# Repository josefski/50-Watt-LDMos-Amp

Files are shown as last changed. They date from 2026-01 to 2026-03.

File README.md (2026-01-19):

# 50-Watt-LDMos-Amp
Inspiration for this project came from here: https://ludens.cl/Electron/50Wamp/50Wamp.html 

A 50 Watt HF Amp that uses modern parts 

This is mostly clanker code for a raspberry pi pico controlled protection loop and operation control for a 50 watt HF Amplifier that uses modern LDmos transistors instead of the IRF series mosfets that are 50 years old and inappropriate for this purpose. 

This is ultimately intended for use as a portable amplifier aimed at SOTA and to a lesser extent POTA operators who want to add some power to their QMX or other QRP radios. The majority of designs available on the internet are built around the IRF 510 or IRF 530 mosfet, and while it's impressive that an hf amp can be built around those parts, they're not very well suited to the purpose. This is designed around the AFT05MP Dual LDmos from NXP, which is currently not recommended for new designs. It's a dual ldmos rf amplifier designed to work up to 530 Mhz. Another rf power transistor that could be substituted would be the BLP5LA55 series LDMOS from Ampleon, which are newer but don't come in the handy dual package. There aren't a lot of 12-15 volt RF mosfets on the market. We're a small niche.  

Principle design goals are as follows: 

-12 volt operation
-Uses actual RF power transistors, preferably ldmos
-No unobtainium parts
-Currently manufactured components only
-Keep parts reasonably affordable
-Smaller heatsink with shortened fins and permanently mounted cooling fans for improved portability 
-Ruggedized, completed design, meaning full protections from drain overvoltage, overcurrent, oscillation, and overtemperature
-Able to be used in line with an antenna tuner!!!!!!!! (Seriously. A portable amp is next to useless without that capability. Finish the design job.) 
-40-10meter operation. Requires only three filter banks. Don't care about the other bands. This is for portable use. 50 watts won't get you over the noise floor on 80 meters anyway.  
-A real Keyer input. No RF sense keying. It's annoying to use. 
-Manual band switching. 
-Always <2:1 input SWR. The amp should never under any circumstance cause the QMX to shut off. 
-Amp shuts off in response to excess current and drain voltage excursions, not high SWR. High SWR doesn't kill transistors. High drain voltage and overcurrent does. 
-Display all relevant parameters and return comprehensible error codes 
-Maybe full QSK. We'll see. Would be nice but not a specific deal breaker. 
-Maybe Variable input attenuation to compensate for QMX low output on 17 and 21 meters. Cool idea but requires some deep thought.

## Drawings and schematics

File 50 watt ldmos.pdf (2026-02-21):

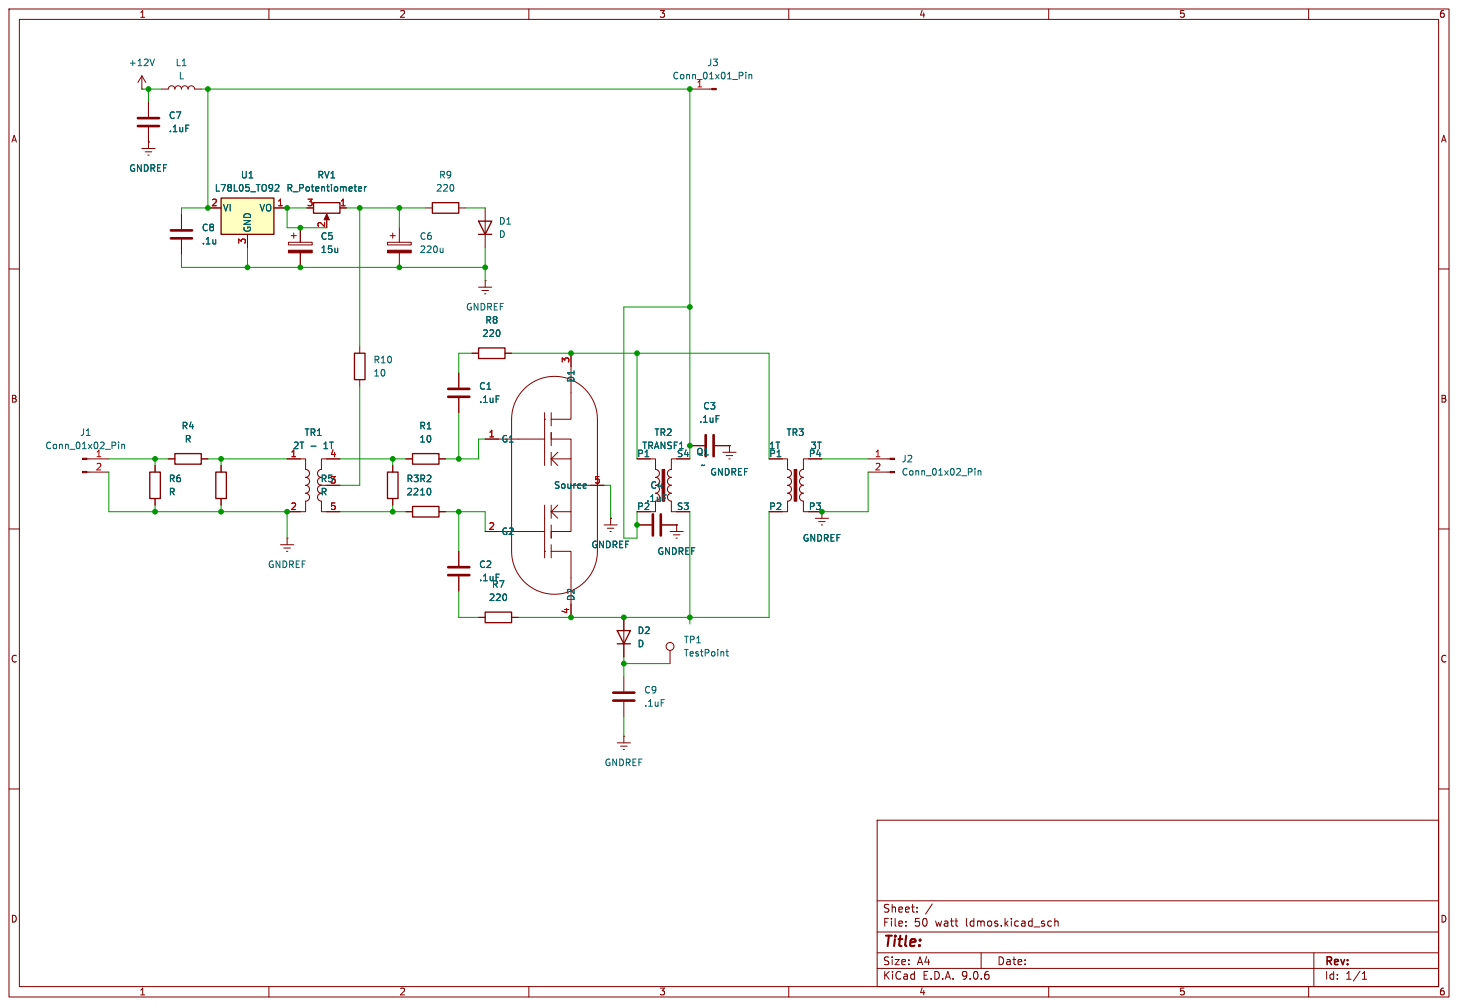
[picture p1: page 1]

4 Source 5 Q1~ R5 R GNDREF VI 2 GND

Id: 1/1 Title: File: 50 watt ldmos.kicad_sch Sheet: /

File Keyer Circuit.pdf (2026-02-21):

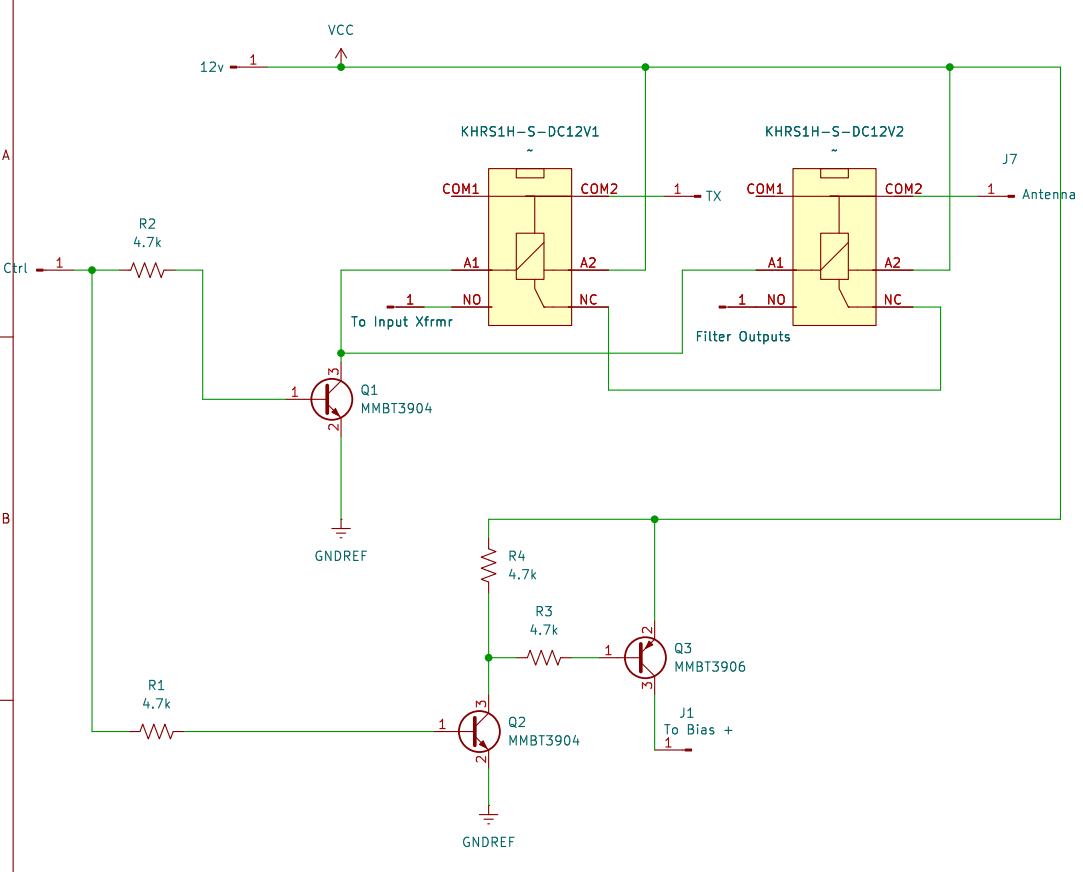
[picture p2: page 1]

Filter Outputs 1 To Input Xfrmr 1

Id: 1/1 Title: File: Keyer Circuit.kicad_sch Sheet: /

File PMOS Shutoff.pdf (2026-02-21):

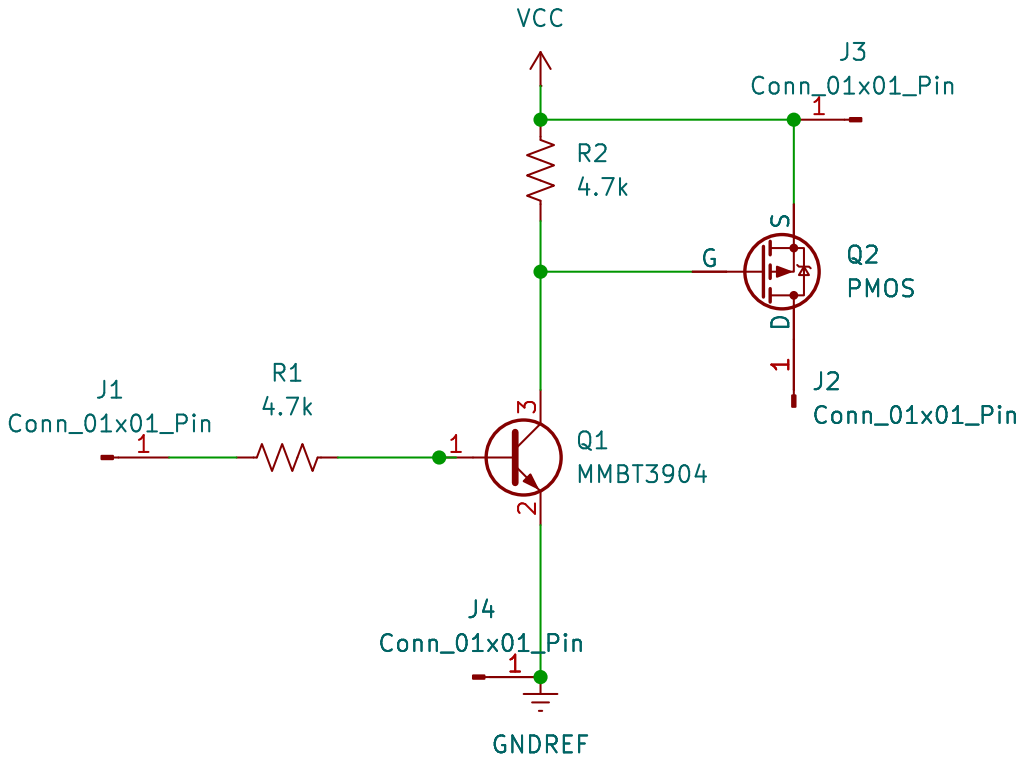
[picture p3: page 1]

Id: 1/1 Title: File: PMOS Shutoff.kicad_sch Sheet: /

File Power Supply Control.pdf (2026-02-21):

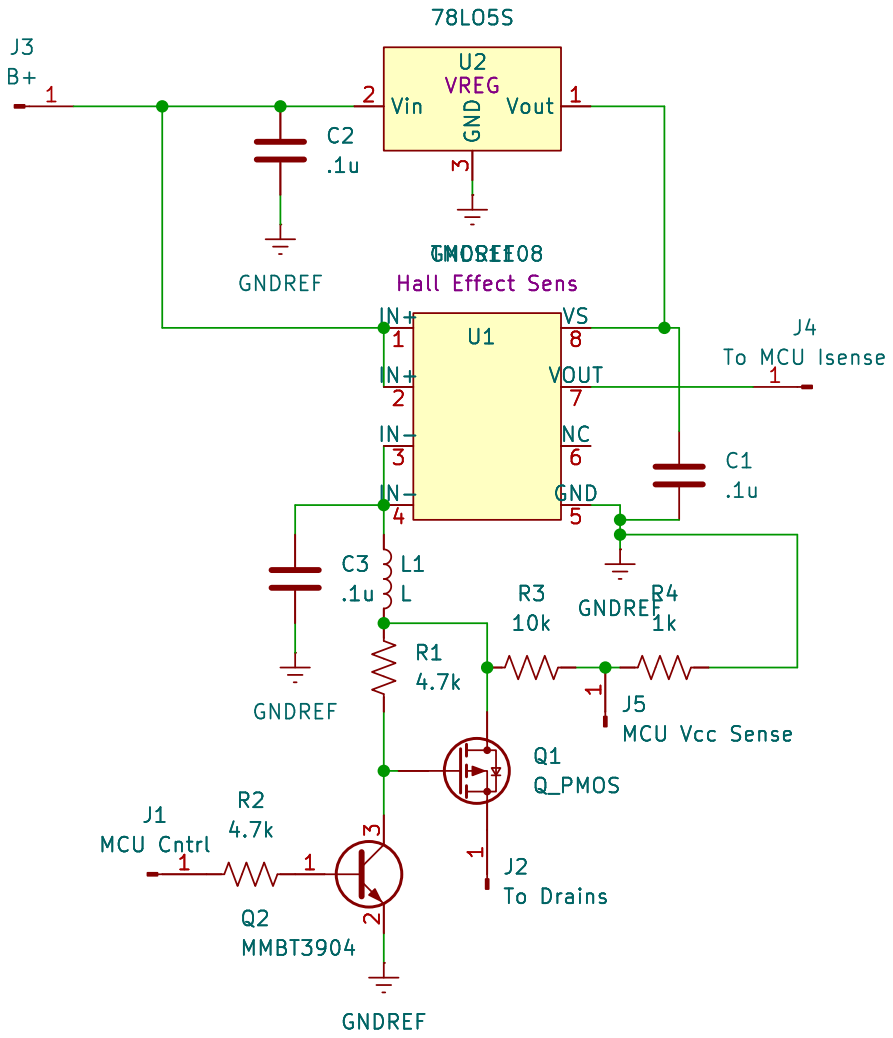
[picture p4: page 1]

J4 To MCU Isense GNDREF
8 VOUT

Id: 1/1 Title: File: Power Supply Control.kicad_sch Sheet: /

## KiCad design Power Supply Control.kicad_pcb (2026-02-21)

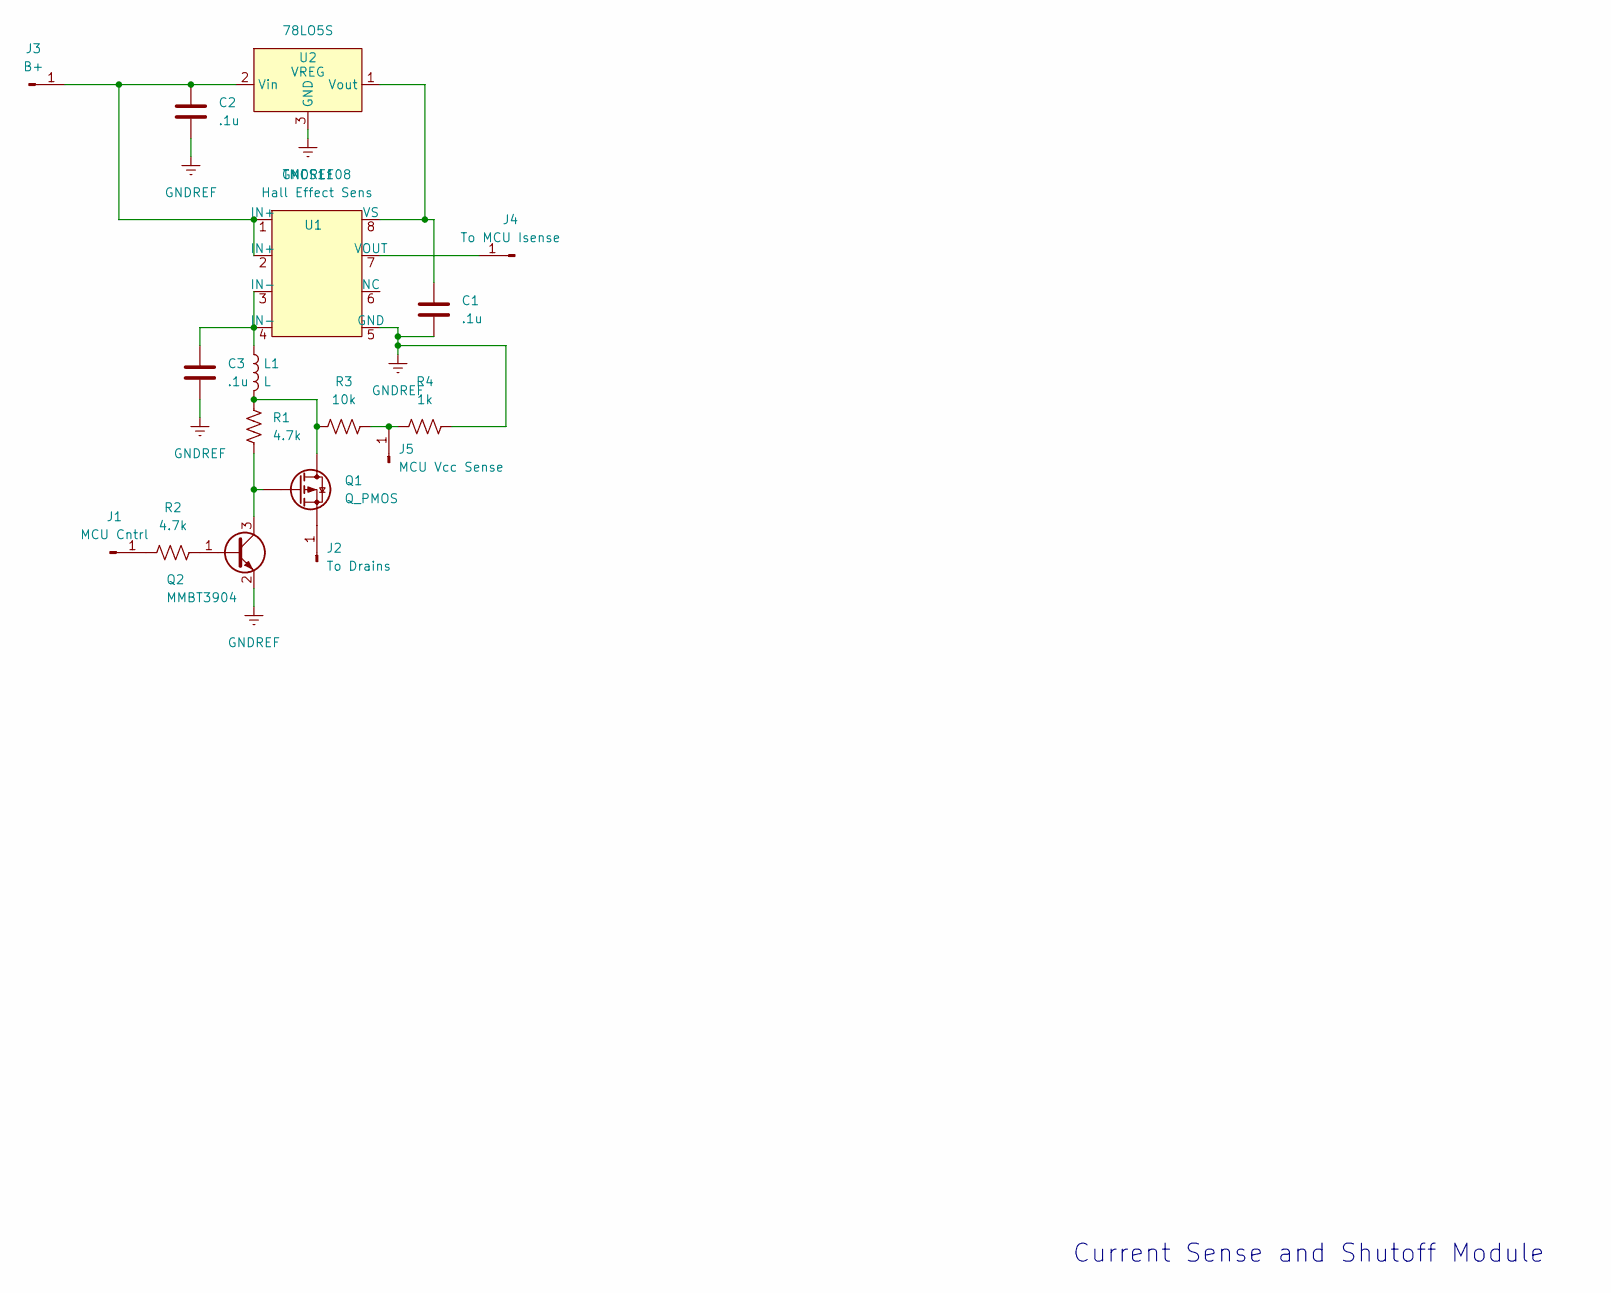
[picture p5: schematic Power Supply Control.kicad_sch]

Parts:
C1, C2: .1u; C_0805_2012Metric_Pad1.18x1.45mm_HandSolder
C3: .1u; .33uF Decoupler HF Amp
J1: MCU Cntrl; Single Surface Mount Header
J2: To Drains; Single Surface Mount Header
J3: B+; Single Surface Mount Header
J4: To MCU Isense; Single Surface Mount Header
J5: MCU Vcc Sense; Single Surface Mount Header
L1: L; Input Choke
Q1: Q_PMOS; Josef TO-252-2
Q2: MMBT3904; SOT-23
R1, R2: 4.7k; R_0805_2012Metric_Pad1.20x1.40mm_HandSolder
R3: 10k; R_0805_2012Metric_Pad1.20x1.40mm_HandSolder
R4: 1k; R_0805_2012Metric_Pad1.20x1.40mm_HandSolder
U1: TMCS1108; SOIC-8 Hall Effect Footprint
U2: 78LO5S; SOT-23

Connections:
GNDREF: C1.2, C2.2, C3.2, Q2.2 (E), R4.2, U1.5 (GND), U2.3 (GND)
unnamed: C3.1, L1.1, U1.3 (IN-), U1.4 (IN-)
unnamed: J1.1, R2.1
unnamed: J2.1, Q1.1 (S)
unnamed: C2.1, J3.1, U1.1 (IN+), U1.2 (IN+), U2.2 (Vin)
unnamed: J4.1, U1.7 (VOUT)
unnamed: J5.1, R3.2, R4.1
unnamed: L1.2, Q1.3 (D), R1.1, R3.1
unnamed: Q1.2 (G), Q2.3 (C), R1.2
unnamed: Q2.1 (B), R2.2
unnamed: C1.1, U1.8 (VS), U2.1 (Vout)

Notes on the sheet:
Current Sense and Shutoff Module

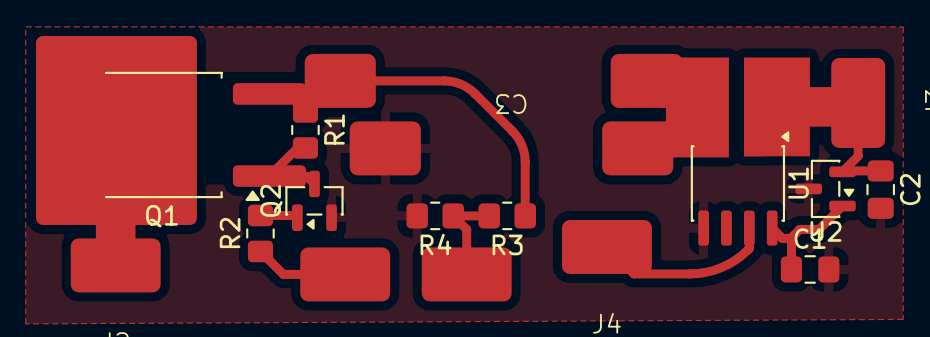
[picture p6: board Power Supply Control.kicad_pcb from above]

Board: 2 copper layers, 17 parts (0 on the bottom side), 11 nets.

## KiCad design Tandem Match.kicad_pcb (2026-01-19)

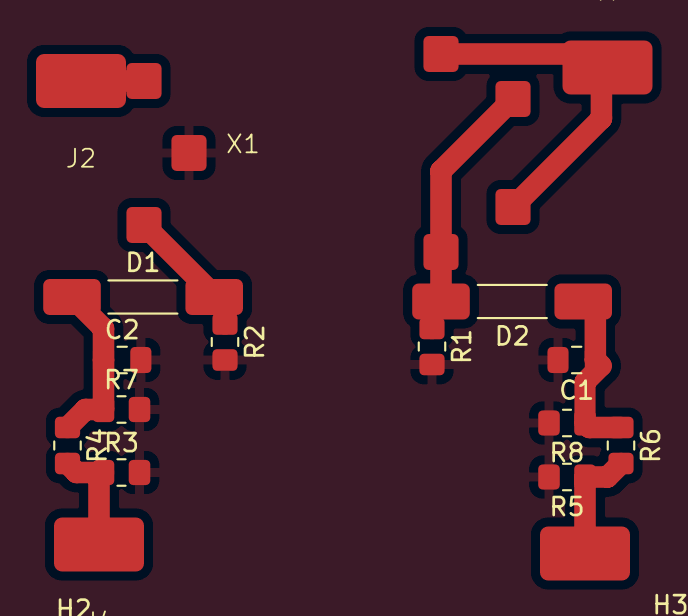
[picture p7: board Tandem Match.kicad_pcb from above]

Board: 2 copper layers, 21 parts (0 on the bottom side), 9 nets.

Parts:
C1, C2: .1u; C_0805_2012Metric_Pad1.18x1.45mm_HandSolder
D1, D2: D; Through Hole Resistor
H1, H2, H3, H4: MountingHole_Pad; MountingHole_3.2mm_M3
J1, J2, J3, J4: Conn_01x01_Pin; Single Surface Mount Header
R1, R2: 50; R_0805_2012Metric_Pad1.20x1.40mm_HandSolder
R3, R5, R7, R8: 10k; R_0805_2012Metric_Pad1.20x1.40mm_HandSolder
R4, R6: 33k; R_0805_2012Metric_Pad1.20x1.40mm_HandSolder
X1: Tandem Match

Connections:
GNDREF: C1.2, C2.2, R1.2, R2.2, R3.2, R5.2, R7.2, R8.2, X1.3 (S)
unnamed: D1.2 (A), R2.1, X1.2
unnamed: C2.1, D1.1 (K), R4.1, R7.1
unnamed: D2.2 (A), R1.1, X1.4, X1.6 (P2_Out)
unnamed: C1.1, D2.1 (K), R6.1, R8.1
unnamed: J1.1, X1.5, X1.7 (P1_Out)
unnamed: J2.1, X1.1
unnamed: J3.1, R5.1, R6.2
unnamed: J4.1, R3.1, R4.2

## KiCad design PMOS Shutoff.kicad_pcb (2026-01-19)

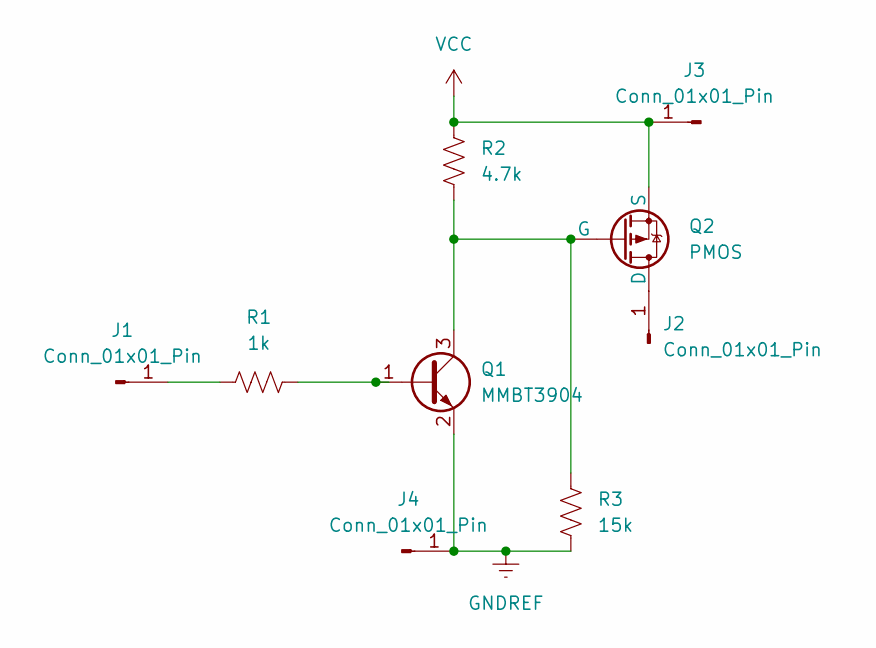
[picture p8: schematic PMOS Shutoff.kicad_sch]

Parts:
J1, J2, J3, J4: Conn_01x01_Pin; Single Surface Mount Header
Q1: MMBT3904; SOT-23
Q2: PMOS; Josef TO-252-2
R1: 1k; R_0805_2012Metric_Pad1.20x1.40mm_HandSolder
R2: 4.7k; R_0805_2012Metric_Pad1.20x1.40mm_HandSolder
R3: 15k; R_0805_2012Metric_Pad1.20x1.40mm_HandSolder

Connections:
GNDREF: J4.1, Q1.2 (E), R3.1
unnamed: J1.1, R1.1
unnamed: J2.1, Q2.1 (D)
unnamed: Q1.1 (B), R1.2
unnamed: Q1.3 (C), Q2.2 (G), R2.1, R3.2
VCC: J3.1, Q2.3 (S), R2.2

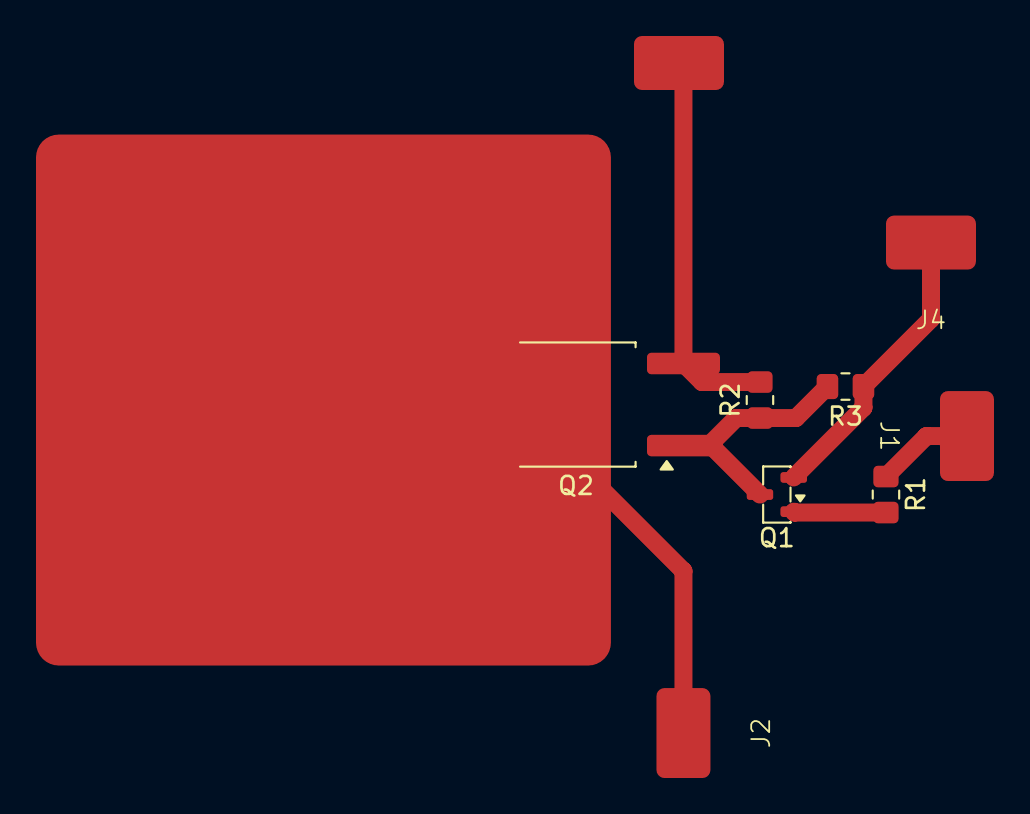
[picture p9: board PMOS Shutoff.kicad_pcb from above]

Board: 2 copper layers, 9 parts (0 on the bottom side), 6 nets.

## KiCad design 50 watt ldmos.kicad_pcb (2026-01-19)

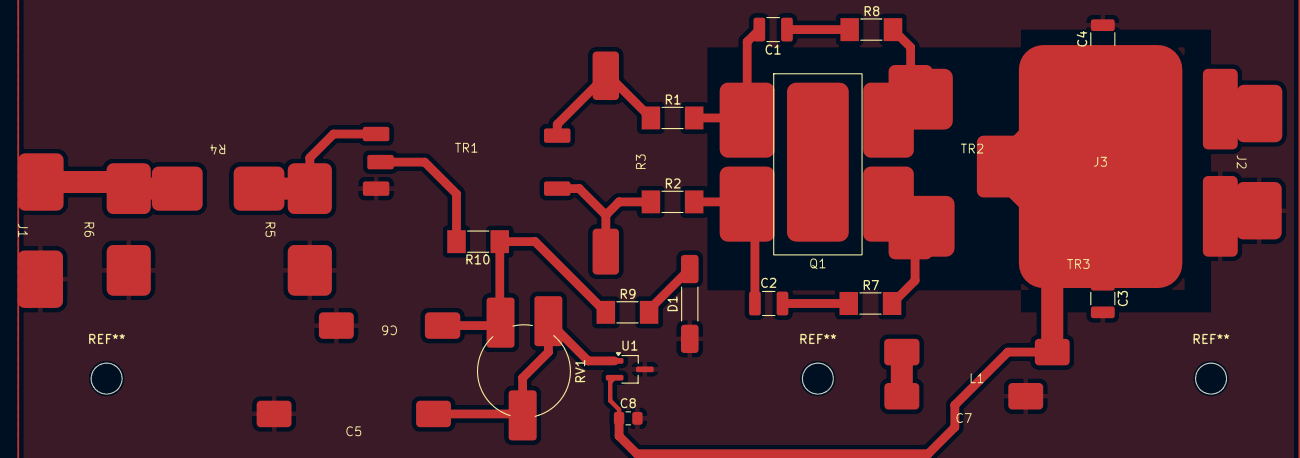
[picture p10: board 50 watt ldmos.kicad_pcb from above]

Board: 2 copper layers, 29 parts (0 on the bottom side), 18 nets.

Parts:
C1, C2, C3, C4: .1uF; C_1210_3225Metric_Pad1.33x2.70mm_HandSolder
C5: 15u; 10uF Radial Cap
C6: 220u; 220 uf Cap
C7: .1uF; .33uF Decoupler HF Amp
C8: .1u; C_0805_2012Metric_Pad1.18x1.45mm_HandSolder
D1: D; Through Hole Resistor
J1, J2: Conn_01x02_Pin; InOutNoHeaders
J3: Conn_01x01_Pin; Positive Plane
L1: L; Input Choke
Q1: AFT05MP
R1, R2, R10: 10; R_MELF_MMB-0207
R3: 22; Big 22ohm Resistor
R4, R5, R6: R; 3550 (Big Resistor) Footprint
R7, R8, R9: 220; R_MELF_MMB-0207
RV1: R_Potentiometer; Piher Surface Pads
TR1: 2T - 1T; Input Transformer
TR2: TRANSF1; Coaxial Feed Transformer
TR3: 1T 3T; Output Transformer
U1: L78L05_TO92; TSOT-23_HandSoldering

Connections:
+12V: C7.1, L1.1
GNDREF: C3.2, C4.2, C5.2, C6.2, C7.2, C8.2, D1.1 (K), J1.2, J2.2, Q1.5 (Source), R5.1, R6.1, TR1.2, TR3.3, U1.3 (GND)
unnamed: C1.1, R8.1
unnamed: C2.2, R7.1
unnamed: C6.1, R9.1, R10.1, RV1.1
unnamed: D1.2 (A), R9.2
unnamed: J1.1, R4.1, R6.2
unnamed: J2.1, TR3.4
unnamed: Q1.3 (D1), R8.2, TR2.1, TR3.1
unnamed: Q1.4 (D2), R7.2, TR2.3 (S3), TR3.2
unnamed: C1.2, Q1.1 (G1), R1.2
unnamed: C2.1, Q1.2 (G2), R2.2
unnamed: R1.1, R3.2, TR1.4
unnamed: R2.1, R3.1, TR1.5
unnamed: R4.2, R5.2, TR1.1
unnamed: R10.2, TR1.3
unnamed: C3.1, C4.1, C8.1, L1.2, TR2.2, TR2.4 (S4), U1.2 (VI)
unnamed: C5.1, RV1.2, RV1.3, U1.1 (VO)

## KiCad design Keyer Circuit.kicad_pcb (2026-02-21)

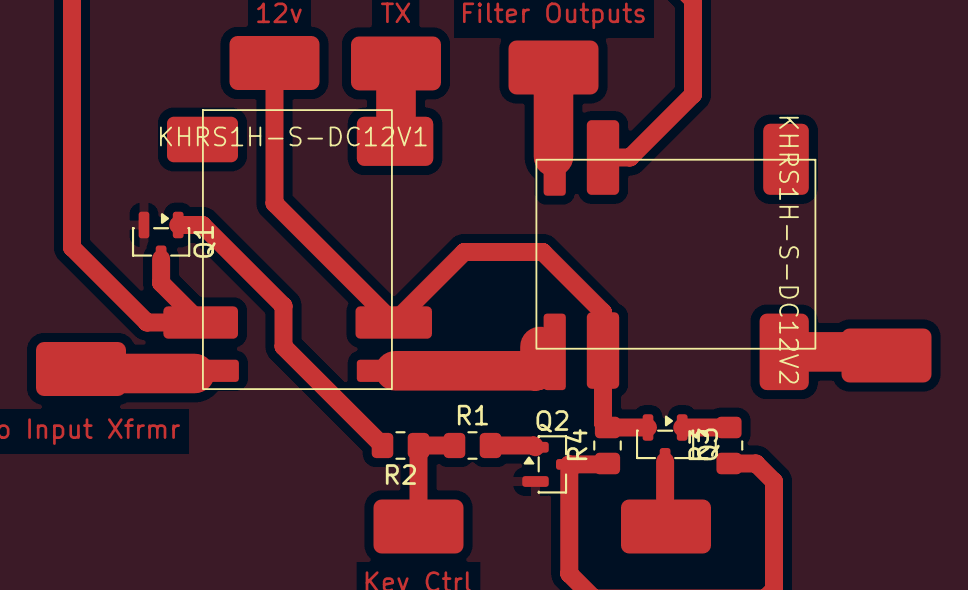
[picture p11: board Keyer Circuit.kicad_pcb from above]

Board: 2 copper layers, 16 parts (0 on the bottom side), 14 nets.

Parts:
J1: To Bias +; Single Surface Mount Header
J2: To Input Xfrmr; Single Surface Mount Header
J3: Key Ctrl; Single Surface Mount Header
J4: Filter Outputs; Single Surface Mount Header
J7: Antenna; Single Surface Mount Header
J8: TX; Single Surface Mount Header
J9: 12v; Single Surface Mount Header
KHRS1H-S-DC12V1, KHRS1H-S-DC12V2: HRS1H Relay No Hole
Q1, Q2: MMBT3904; SOT-23
Q3: MMBT3906; SOT-23
R1, R2, R3, R4: 4.7k; R_0805_2012Metric_Pad1.20x1.40mm_HandSolder

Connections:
GNDREF: Q1.2 (E), Q2.2 (E)
unnamed: J1.1, Q3.3 (C)
unnamed: J2.1, KHRS1H-S-DC12V1.NO
unnamed: J3.1, R1.1, R2.1
unnamed: J4.1, KHRS1H-S-DC12V2.NO
unnamed: J7.1, KHRS1H-S-DC12V2.COM2
unnamed: J8.1, KHRS1H-S-DC12V1.COM2
unnamed: KHRS1H-S-DC12V1.NC, KHRS1H-S-DC12V2.NC
unnamed: Q1.1 (B), R2.2
unnamed: KHRS1H-S-DC12V1.A1, KHRS1H-S-DC12V2.A1, Q1.3 (C)
unnamed: Q2.1 (B), R1.2
unnamed: Q2.3 (C), R3.1, R4.1
unnamed: Q3.1 (B), R3.2
VCC: J9.1, KHRS1H-S-DC12V1.A2, KHRS1H-S-DC12V2.A2, Q3.2 (E), R4.2

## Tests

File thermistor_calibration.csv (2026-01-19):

Temperature | 31.5 | 36 | 39 | 40 | 45 | 66.8 | 68 | 70 | 80 | 90 | 100 | 110 | 120 | 130 | 140 | 150 | 160 | 170 | 180 | 190 | 200 | 210 | 212
Resistance | 27100 | 25000 | 24000 | 21000 | 17800 | 10200 | 9800 | 9100 | 7000 | 5600 | 4700 | 3800 | 3100 | 2700 | 2200 | 1860 | 1500 | 1420 | 1250 | 1100 | 970 | 860 | 850

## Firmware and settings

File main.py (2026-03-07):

from machine import I2C, Pin
import utime

import a2d
import config
import v_drain
import current_sense
import swr_calc
import Vcc
import control
import thermistor
import band_switch
import keyer
import display
import display_config as dc


# --- Hardware bring-up ---
i2c = I2C(
    config.I2C_ID,
    scl=Pin(config.I2C_SCL_PIN),
    sda=Pin(config.I2C_SDA_PIN),
    freq=config.I2C_FREQ_HZ
)

ads = a2d.ADS1115(i2c, address=config.ADS1115_ADDR)
if not ads.probe():
    raise RuntimeError("ADS1115 not found on I2C")

vdrain = v_drain.VDrain(
    adc_channel=config.VDRAIN_ADC_CH,
    scale=config.VDRAIN_SCALE
)

isense = current_sense.CurrentSense(
    adc_channel=config.CURRENT_ADC_CH,
    offset_v=config.CURRENT_OFFSET_V,
    v_per_a=config.CURRENT_V_PER_A
)

swr = swr_calc.SWRCalc(
    ads1115=ads,
    fwd_channel=config.ADS_FWD_CH,
    rfl_channel=config.ADS_RFL_CH,
    pga=config.ADS_PGA,
    data_rate=config.ADS_DATA_RATE,
    table_path=config.SWR_TABLE_PATH
)

temp = thermistor.ThermistorADS(
    ads1115=ads,
    channel=config.THERM_ADS_CH,
    csv_path=config.THERM_TABLE,
    vref=config.THERM_VREF,
    r_fixed=config.THERM_R_FIXED,
    pga=config.THERM_ADS_PGA,
    data_rate=config.THERM_ADS_DATA_RATE
)

vcc = Vcc.Vcc(
    adc_channel=config.VCC_ADC_CH,
    scale=config.VCC_SCALE
)

# --- LCD ---
i2c_lcd = I2C(1, sda=Pin(2), scl=Pin(3), freq=100000)
disp = display.Display(i2c_lcd)

# --- Control I/O ---
protect_out = Pin(config.PROTECT_GPIO, Pin.OUT)
bands = band_switch.BandSwitch(config)

reset_in = Pin(
    config.RESET_GPIO,
    Pin.IN,
    Pin.PULL_UP if config.RESET_PULL == "UP" else Pin.PULL_DOWN
)

tx_en_out = Pin(config.TX_EN_GPIO, Pin.OUT)

# Default TX_EN OFF at boot
tx_en_out.value(0 if config.TX_EN_ACTIVE_HIGH else 1)

ptt = keyer.Keyer(
    config.KEYER_GPIO,
    active_low=config.KEYER_ACTIVE_LOW,
    pull=config.KEYER_PULL
)
ptt._debounce_ms = config.KEYER_DEBOUNCE_MS

ctrl = control.AmpControl(config)

# Default OFF at boot => assert disable output
protect_out.value(1 if config.PROTECT_ACTIVE_HIGH else 0)

# --- Scheduling ---
t_print = utime.ticks_ms()
t_fast = utime.ticks_ms()
t_swr = utime.ticks_ms()
t_therm = utime.ticks_ms()
t_lcd = utime.ticks_ms()

latest = {
    "pfwd_w": 0.0,
    "prfl_w": 0.0,
    "swr": float("inf"),
    "samples": 0,
    "vDrain": 0.0,
    "iDrain": 0.0,
    "vcc": 0.0,
    "temp_c": 0.0,
    "ptt": False,

    # keep RF volts as state (do NOT reset each loop)
    "vfwd_v": 0.0,
    "vrfl_v": 0.0,
}

state = {
    "disable": True,
    "amp_enabled": False,
    "tripped": False,
    "reason": "OK",
    "band_idx": config.BAND_DEFAULT_INDEX,
    "ptt": False,
}

band_idx = config.BAND_DEFAULT_INDEX

# IIR filter coefficient for RF detector volts (0<alpha<=1). Higher = faster response, noisier.
alpha = 0.2

# --- Hot-path aliases / cached constants ---
ticks_ms = utime.ticks_ms
ticks_diff = utime.ticks_diff
sleep_ms = utime.sleep_ms

read_ptt = ptt.update
is_keyed = ptt.is_keyed
read_reset = reset_in.value
update_band = bands.update
update_ctrl = ctrl.update
update_display = disp.update

read_vdrain = vdrain.read_drain_voltage
read_idrain = isense.read_current
read_vcc = vcc.read_vcc_voltage
read_temp = temp.read_temperature
read_ads_voltage = ads.read_voltage
interp_watts = swr.v_to_w.interp
swr_from_powers = swr_calc.swr_from_powers

fast_telem_ms = config.FAST_TELEM_MS
swr_avg_window_ms = config.SWR_AVG_WINDOW_MS
therm_telem_ms = config.THERM_TELEM_MS
lcd_refresh_ms = dc.LCD_REFRESH_MS
print_period_ms = config.PRINT_PERIOD_MS

ads_fwd_ch = config.ADS_FWD_CH
ads_rfl_ch = config.ADS_RFL_CH
ads_pga = config.ADS_PGA
ads_data_rate = config.ADS_DATA_RATE

protect_level_when_disabled = 1 if config.PROTECT_ACTIVE_HIGH else 0
protect_level_when_enabled = 0 if config.PROTECT_ACTIVE_HIGH else 1
tx_level_when_enabled = 1 if config.TX_EN_ACTIVE_HIGH else 0
tx_level_when_disabled = 0 if config.TX_EN_ACTIVE_HIGH else 1

last_protect_level = None
last_tx_level = None

while True:
    now = ticks_ms()

    # --- FAST LOOP ---
    read_ptt(now_ms=now)
    keyed = is_keyed()

    if not keyed:
        band_idx = update_band(now_ms=now)

    state = update_ctrl(latest, now_ms=now, reset_btn_level=read_reset())
    state["band_idx"] = band_idx
    state["ptt"] = keyed
    latest["ptt"] = keyed

    # Drive protection output (disable asserted when state["disable"] is True)
    protect_level = protect_level_when_disabled if state["disable"] else protect_level_when_enabled
    if protect_level != last_protect_level:
        protect_out.value(protect_level)
        last_protect_level = protect_level

    # TX enable policy: keyed AND amp allowed
    tx_en = bool(keyed and (not state["disable"]))
    tx_level = tx_level_when_enabled if tx_en else tx_level_when_disabled
    if tx_level != last_tx_level:
        tx_en_out.value(tx_level)
        last_tx_level = tx_level

    # --- FAST TELEMETRY ---
    if ticks_diff(now, t_fast) >= fast_telem_ms:
        t_fast = now
        latest["vDrain"] = read_vdrain()
        latest["iDrain"] = read_idrain()
        latest["vcc"] = read_vcc()

    # --- RF TELEMETRY (non-blocking) ---
    if ticks_diff(now, t_swr) >= swr_avg_window_ms:
        t_swr = now

        vfwd = read_ads_voltage(ads_fwd_ch, pga=ads_pga, data_rate=ads_data_rate)
        vrfl = read_ads_voltage(ads_rfl_ch, pga=ads_pga, data_rate=ads_data_rate)

        # IIR low-pass on detector volts
        latest["vfwd_v"] = latest["vfwd_v"] + alpha * (vfwd - latest["vfwd_v"])
        latest["vrfl_v"] = latest["vrfl_v"] + alpha * (vrfl - latest["vrfl_v"])

        # Volts -> Watts using calibration curve
        pfwd_w = interp_watts(latest["vfwd_v"])
        prfl_w = interp_watts(latest["vrfl_v"])
        if pfwd_w < 0.0:
            pfwd_w = 0.0
        if prfl_w < 0.0:
            prfl_w = 0.0

        latest["pfwd_w"] = pfwd_w
        latest["prfl_w"] = prfl_w
        latest["swr"] = swr_from_powers(pfwd_w, prfl_w)
        latest["samples"] = 1

    # --- THERMAL ---
    if ticks_diff(now, t_therm) >= therm_telem_ms:
        t_therm = now
        latest["temp_c"] = read_temp()

    # --- LCD ---
    if ticks_diff(now, t_lcd) >= lcd_refresh_ms:
        t_lcd = now
        update_display(latest, state, now_ms=now)

    # --- PRINT ---
    if ticks_diff(now, t_print) >= print_period_ms:
        t_print = now
        print(
            "PTT=", keyed,
            "AMP=", "ON" if state["amp_enabled"] else "OFF",
            "PROT=", ("TRIP:" + state["reason"]) if state["tripped"] else "OK",
            "Pfwd=", latest["pfwd_w"], "W",
            "SWR=", latest["swr"],
            "Vfwd=", latest["vfwd_v"], "V",
            "Vrfl=", latest["vrfl_v"], "V",
            "Vcc=", latest["vcc"],
            "I=", latest["iDrain"],
            "Vd=", latest["vDrain"],
            "T=", latest["temp_c"],
            "BAND=", band_idx + 1,
            "FWD_CH=", ads_fwd_ch,
            "RFL_CH=", ads_rfl_ch
        )

    sleep_ms(1)

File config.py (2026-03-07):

# Central configuration for Pico HF Amp controller

import a2d

# --- I2C / ADS1115 wiring ---
I2C_ID = 0
I2C_SCL_PIN = 17
I2C_SDA_PIN = 16
I2C_FREQ_HZ = 400_000
ADS1115_ADDR = 0x48

# --- ADS1115 channels ---
ADS_FWD_CH = 3
ADS_RFL_CH = 0

# --- ADS1115 measurement settings ---
ADS_PGA = a2d.PGA_4_096V
ADS_DATA_RATE = a2d.DR_860SPS

# --- Pico internal ADC channels ---
VDRAIN_ADC_CH = 0   # ADC0 / GP26
CURRENT_ADC_CH = 1  # ADC1 / GP27
VCC_ADC_CH = 2      # ADC2 / GP28

# --- Scaling ---
VDRAIN_SCALE = 17.5853  # calibrated: was 16.6666 (read 12.7V, actual 13.4V)
VCC_SCALE = 15.05

CURRENT_OFFSET_V = 0.5
CURRENT_V_PER_A  = 0.1

# --- Processing cadence ---
SWR_AVG_WINDOW_MS = 10
PRINT_PERIOD_MS = 500
FAST_TELEM_MS = 10
THERM_TELEM_MS = 500

# --- Calibration files ---
SWR_TABLE_PATH = "swr_table.csv"
THERM_TABLE = "thermistor_calibration.csv"

# --- Protection output ---
PROTECT_GPIO = 14
PROTECT_ACTIVE_HIGH = False

# --- Manual reset input ---
RESET_GPIO = 13
RESET_ACTIVE_LOW = True
RESET_PULL = "UP"
RESET_DEBOUNCE_MS = 10

# --- Protection thresholds ---
PROTECT_VDRAIN_MAX_V = 35.0
PROTECT_IDRAIN_MAX_A = 9
PROTECT_FWD_MIN_FRACTION = 0.1
PROTECT_MIN_I_FOR_EFF_A = 5
PROTECT_MIN_TOTAL_POWER_W = 50.0
PROTECT_TRIP_DEBOUNCE_MS = 200

# --- Thermal protection ---
PROTECT_TEMP_MAX_C = 40.0
PROTECT_THERM_DEBOUNCE_MS = 5000

# --- Thermistor wiring ---
THERM_ADS_CH = 2
THERM_VREF = 3.3
THERM_R_FIXED = 4700.0
THERM_ADS_PGA = ADS_PGA
THERM_ADS_DATA_RATE = ADS_DATA_RATE

# --- Band switching ---
BAND_GPIO_PINS = (4, 5, 6)         
BAND_ACTIVE_HIGH = True        # compatibility for band_switch.py

BAND_BUTTON_GPIO = 7
BAND_BUTTON_ACTIVE_LOW = True
BAND_BUTTON_PULL = "UP"
BAND_BUTTON_DEBOUNCE_MS = 10
BAND_DEFAULT_INDEX = 0

# --- Keyer / PTT ---
KEYER_GPIO = 12                 # <-- set to your PTT/key line
KEYER_ACTIVE_LOW = True         # shorts to GND when keyed
KEYER_PULL = "UP"
KEYER_DEBOUNCE_MS = 10

# --- TX enable output (drives NPN buffer / bias enable / TX relays) ---
TX_EN_GPIO = 15               # <-- choose a free GPIO you wired to your NPN/PNP driver
TX_EN_ACTIVE_HIGH = True      # True: GPIO=1 asserts TX_EN

# --- Display smoothing / peak-hold ---
DISP_HOLD_MS = 600          # how long to freeze the peak
DISP_DECAY_PER_SEC = 0.65   # fraction per second toward live value (0..1), higher=snappier
DISP_WORST_SWR_HOLD = True  # hold worst (max) SWR

# Hold TX_EN on for this long after PTT/key releases (prevents relay chatter on CW)
KEYER_HANG_MS = 200   # typical 150–300ms; start at 200ms

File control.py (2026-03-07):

# control.py
# Combined amp enable toggle + latched protection (manual clear)
#
# Output behavior:
#   output_disable == True  => drive protection/disable output (amp OFF)
#   output_disable == False => allow amp ON
#
# Policy:
#   - Boot defaults to amp OFF
#   - Button press toggles amp ON/OFF when NOT tripped
#   - If tripped, button press clears fault latch BUT amp remains OFF
#   - Trips latch on any fault condition (debounced)

import utime


class AmpControl:
    def __init__(self, cfg):
        self.cfg = cfg
        
        self._therm_start_ms = None


        # Default: amp OFF at boot
        self.amp_enabled = False

        # Protection latch
        self.tripped = False
        self.last_reason = "OK"

        # Debounce state
        self._fault_start_ms = None
        self._btn_last_level = None
        self._btn_last_change_ms = None
        self._btn_press_consumed = False  # ensures one action per press

    def _btn_is_pressed(self, level):
        # level is raw GPIO read (0/1)
        return (level == 0) if self.cfg.RESET_ACTIVE_LOW else (level == 1)

    def _fault_reason(self, telemetry):
        v_drain = telemetry["vDrain"]
        i_drain = telemetry["iDrain"]
        vcc     = telemetry["vcc"]
        pfwd    = telemetry["pfwd_w"]

        if v_drain > self.cfg.PROTECT_VDRAIN_MAX_V:
            return True, "VDRAIN_OV"

        if i_drain > self.cfg.PROTECT_IDRAIN_MAX_A:
            return True, "IDRAIN_OC"

        total_p = vcc * i_drain
        if (i_drain >= self.cfg.PROTECT_MIN_I_FOR_EFF_A) and (total_p >= self.cfg.PROTECT_MIN_TOTAL_POWER_W):
            min_pfwd = self.cfg.PROTECT_FWD_MIN_FRACTION * total_p
            if pfwd < min_pfwd:
                return True, "FWD_LOW_VS_VI"

        return False, "OK"


    def _debounced_button_event(self, now_ms, level):
        """
        Returns True exactly once per debounced press.
        """
        if self._btn_last_level is None:
            self._btn_last_level = level
            self._btn_last_change_ms = now_ms
            return False

        if level != self._btn_last_level:
            self._btn_last_level = level
            self._btn_last_change_ms = now_ms
            self._btn_press_consumed = False
            return False

        # Stable level for >= debounce interval
        if utime.ticks_diff(now_ms, self._btn_last_change_ms) < self.cfg.RESET_DEBOUNCE_MS:
            return False

        pressed = self._btn_is_pressed(level)

        # One event per press
        if pressed and not self._btn_press_consumed:
            self._btn_press_consumed = True
            return True

        # When released, allow next press to generate event
        if not pressed:
            self._btn_press_consumed = False

        return False

    def update(self, telemetry, now_ms, reset_btn_level):
        """
        Returns a dict describing the control state:
          {
            "disable": bool,        # True => force amp OFF (assert disable output)
            "amp_enabled": bool,    # requested enable (if not tripped)
            "tripped": bool,
            "reason": str
          }
        """
        # 1) Evaluate electrical protection (fast debounce) and latch on trip
        is_fault, reason = self._fault_reason(telemetry)

        if not self.tripped:
            if is_fault:
                if self._fault_start_ms is None:
                    self._fault_start_ms = now_ms
                elif utime.ticks_diff(now_ms, self._fault_start_ms) >= self.cfg.PROTECT_TRIP_DEBOUNCE_MS:
                    self.tripped = True
                    self.last_reason = reason
                    self.amp_enabled = False
            else:
                self._fault_start_ms = None

        # 2) Thermal protection (slow debounce) - trips only if sustained overtemp
        temp_c = telemetry["temp_c"]
        overtemp = temp_c >= self.cfg.PROTECT_TEMP_MAX_C

        if not self.tripped:
            if overtemp:
                if self._therm_start_ms is None:
                    self._therm_start_ms = now_ms
                elif utime.ticks_diff(now_ms, self._therm_start_ms) >= self.cfg.PROTECT_THERM_DEBOUNCE_MS:
                    self.tripped = True
                    self.last_reason = "THERM_OT"
                    self.amp_enabled = False
            else:
                self._therm_start_ms = None
        else:
            self._therm_start_ms = None

        # 3) Handle button press event
        pressed_event = self._debounced_button_event(now_ms, reset_btn_level)
        if pressed_event:
            if self.tripped:
                # Clear trip latch, but keep amp OFF (requires second press to enable)
                self.tripped = False
                self.last_reason = "OK"
                self._fault_start_ms = None
                self._therm_start_ms = None
                self.amp_enabled = False
            else:
                # Toggle enable state
                self.amp_enabled = not self.amp_enabled

        # 4) Determine output disable state
        disable = (not self.amp_enabled) or self.tripped

        return {
            "disable": disable,
            "amp_enabled": self.amp_enabled,
            "tripped": self.tripped,
            "reason": (self.last_reason if self.tripped else "OK")
        }

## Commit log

2026-01-19 Add swr_table.csv detector calibration
    [swr_table.csv]
2026-02-04 Refactor display for 16x2 I2C LCD; update main to publish band index to display state
2026-02-08 Display: switch to 16x2 layout; publish band index; add keyer skeleton
2026-02-08 Update LCD renderer for 16x2 I2C display
2026-02-21 PDF, pcb, and sch files for various modules.
    The schematic files should look familiar. The PCB's may look strange as they're intended to not require any drilling. All through hole component are treated as surface mount. Bend the leads and solde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
    [Keyer Circuit.kicad_pcb, Power Supply Control.kicad_pcb, Power Supply Control.kicad_sch]
2026-03-05 Add ATU-100 tuning mode with switchable input attenuator
    Implements a tuning mode state machine that inserts an attenuator on the
    amp input, triggers a tuning cycle on the integrated ATU-100, waits for
    completion (via busy signal or timeout), then removes the attenuator.
    New module tune_mode.py (TuneMode class):
    - 5-state machine: IDLE -> ATT_IN -> TRIGGER -> WAITING -> ATT_OUT -> IDLE
    - Dedicated button (GP8) starts sequence only when amp is enabled and healthy
    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
2026-03-05 Revert "Add ATU-100 tuning mode with switchable input attenuator"
    This reverts commit 91d47519f2229c1e908ea2e09ab52de9c08fcdd6.
    [config.py, control.py, display.py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]
2026-03-06 Optimize and clean up across modules
    - control.py: remove unreachable thermal dead-code block after return in
    _fault_reason(); switch telemetry dict access from .get() to direct []
    in both _fault_reason() and update() for hot-path speed
    - v_drain.py, Vcc.py, current_sense.py: collapse per-read ADC arithmetic
    into a single precomputed constant (_K) at __init__; each read is now
    one multiply instead of two divides + a multiply
    - thermistor.py: resolve pga/data_rate defaults at __init__ (importing
    from a2d) and collapse four-branch read_adc_voltage() to one call
    - interp.py: extract shared PiecewiseLinear into its own module using
    bisect for O(log n) lookup instead of O(n) linear sc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
    [Vcc.py, band_switch.py, control.py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]
2026-03-07 Recalibrate drain voltage scale factor
    Was reading 12.7V at an actual 13.4V supply.
    New scale = 16.6666 * (13.4 / 12.7) = 17.5853.
    https://claude.ai/code/session_017ST951dEHBYPp529hkpVfW
2026-03-07 Fix display blank: replace bisect with inline binary search in interp.py
    bisect.bisect_right() can crash at runtime on some MicroPython builds
    when passed a regular Python list, even though the module imports fine.
    The t_swr block fires 10 ms into the main loop -- well before the first
    250 ms LCD update -- so the crash leaves the display permanently blank
    after the startup splash.
    Replace with a pure-Python binary search that is guaranteed to work on
    all MicroPython targets.
    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
    [interp.py]
